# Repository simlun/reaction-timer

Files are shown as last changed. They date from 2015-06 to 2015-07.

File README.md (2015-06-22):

Reaction Timer
==============

A complete product based on Experiment 18 of [Make Electronics by Charles Platt][makeelec] - the Reaction Timer.

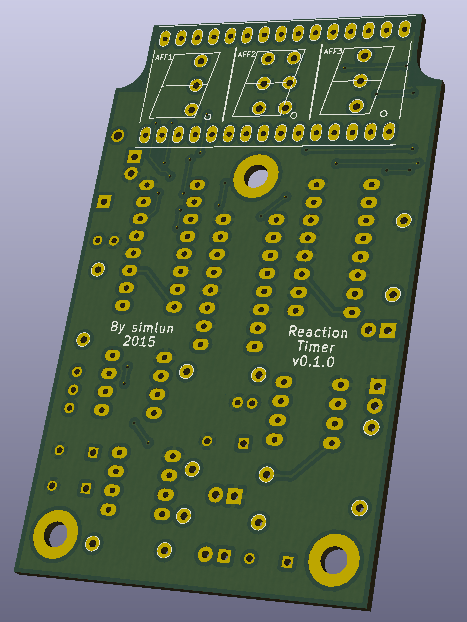
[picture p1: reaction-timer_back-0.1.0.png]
Back


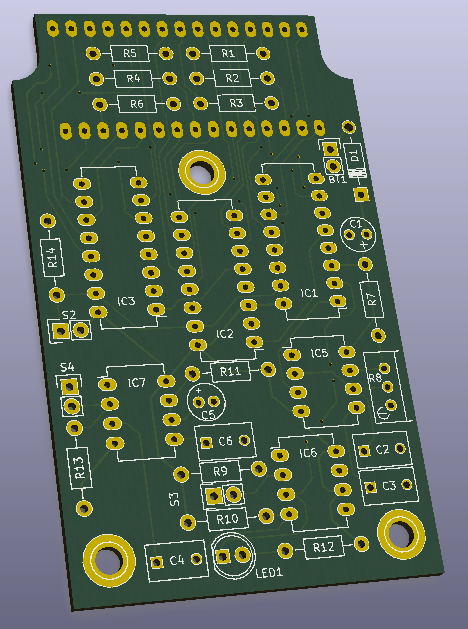
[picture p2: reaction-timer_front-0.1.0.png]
Front


My Modifications
----------------

* A real PCB design based on Platt's circuit diagrams and breadboarded version.
* Instead of `IC4`, the 3-in-1 package Platt is using, I'm using 3 separate 7-segment LED display modules (`IC4a-c`).
* I'm using a 5.6 kOhm `R12` as the current limiting resistor for the LED instead of Platt's 1 kOhms.
* There are two `R10`'s in the circuit diagram on [page 178][makeelec]. The one that is connected to `IC7` will be called `R13` here.

Bill Of Materials
-----------------

* Case: Hammond Manufacturing 1591CTCL clear polycarbonate box
* Power: 9 V battery connector cable
* `D1`: Reverse voltage protection 1N4004 diode

* `IC1`, `IC2`, `IC3`: DIP-16 4026 decade counters with 7-segment display driver
* `IC4a`, `IC4b`, `IC4c`: 7-segment 14 mm common cathode LED display
* `IC5`, `IC6`, `IC7`: DIP-8 555 timers

* `LED1`: Red LED

* `S2`, `S3`, `S4`: Normally open push buttons

* `C1`: 100 uF capacitor
* `C2`, `C3`, `C4`, `C6`: 0.1 uF capacitor
* `C5`: 10 uF capacitor

* `R1`, `R2`, `R3`, `R4`, `R5`, `R6`: 1 kOhm LED display current limiting resistors
* `R7`: 1 kOhm resistor for calibrating the clock timer (`IC5`)
* `R8`: 10 kOhm trimmer potentiometer for calibrating the clock timer (`IC5`)
* `R9`, `R10`, `R13`: 1 kOhm pull-up resistors
* `R14`: 1 kOhm pull-down resistor
* `R11`: 330 kOhm resistor for calibrating the delay timer (`IC7`)
* `R12`: 5.6 kOhm resistor

[makeelec]: http://www.amazon.com/Make-Electronics-Discovery-Charles-Platt/dp/0596153740

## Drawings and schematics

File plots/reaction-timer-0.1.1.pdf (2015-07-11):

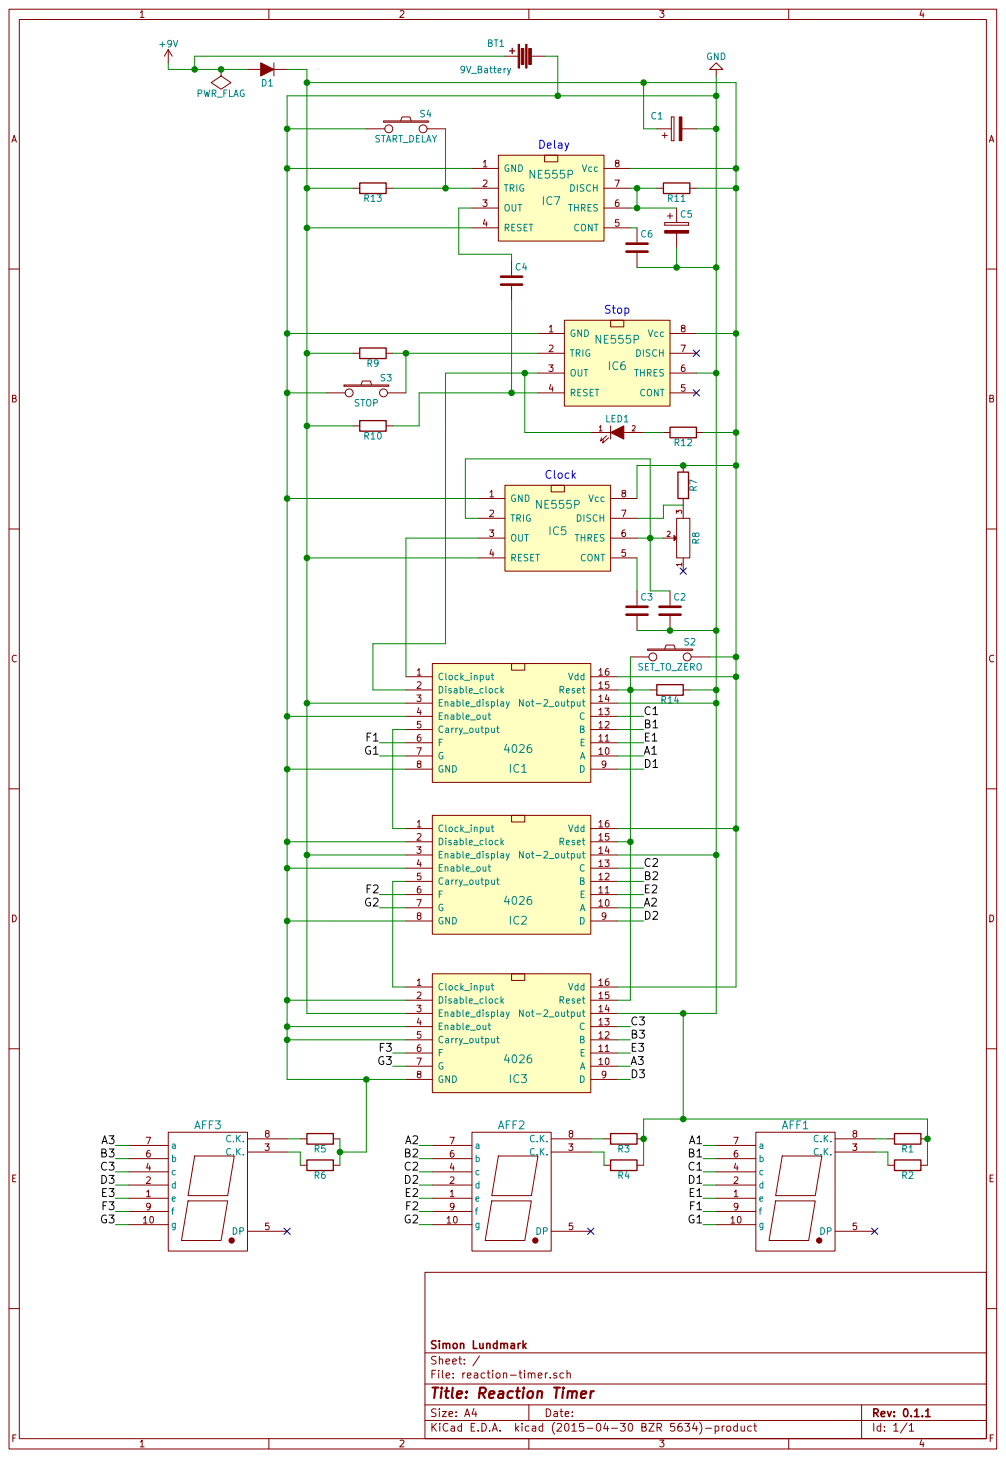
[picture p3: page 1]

Id: 1/1 Title: Reaction Timer File: reaction-timer.sch Sheet: / Simon Lundmark

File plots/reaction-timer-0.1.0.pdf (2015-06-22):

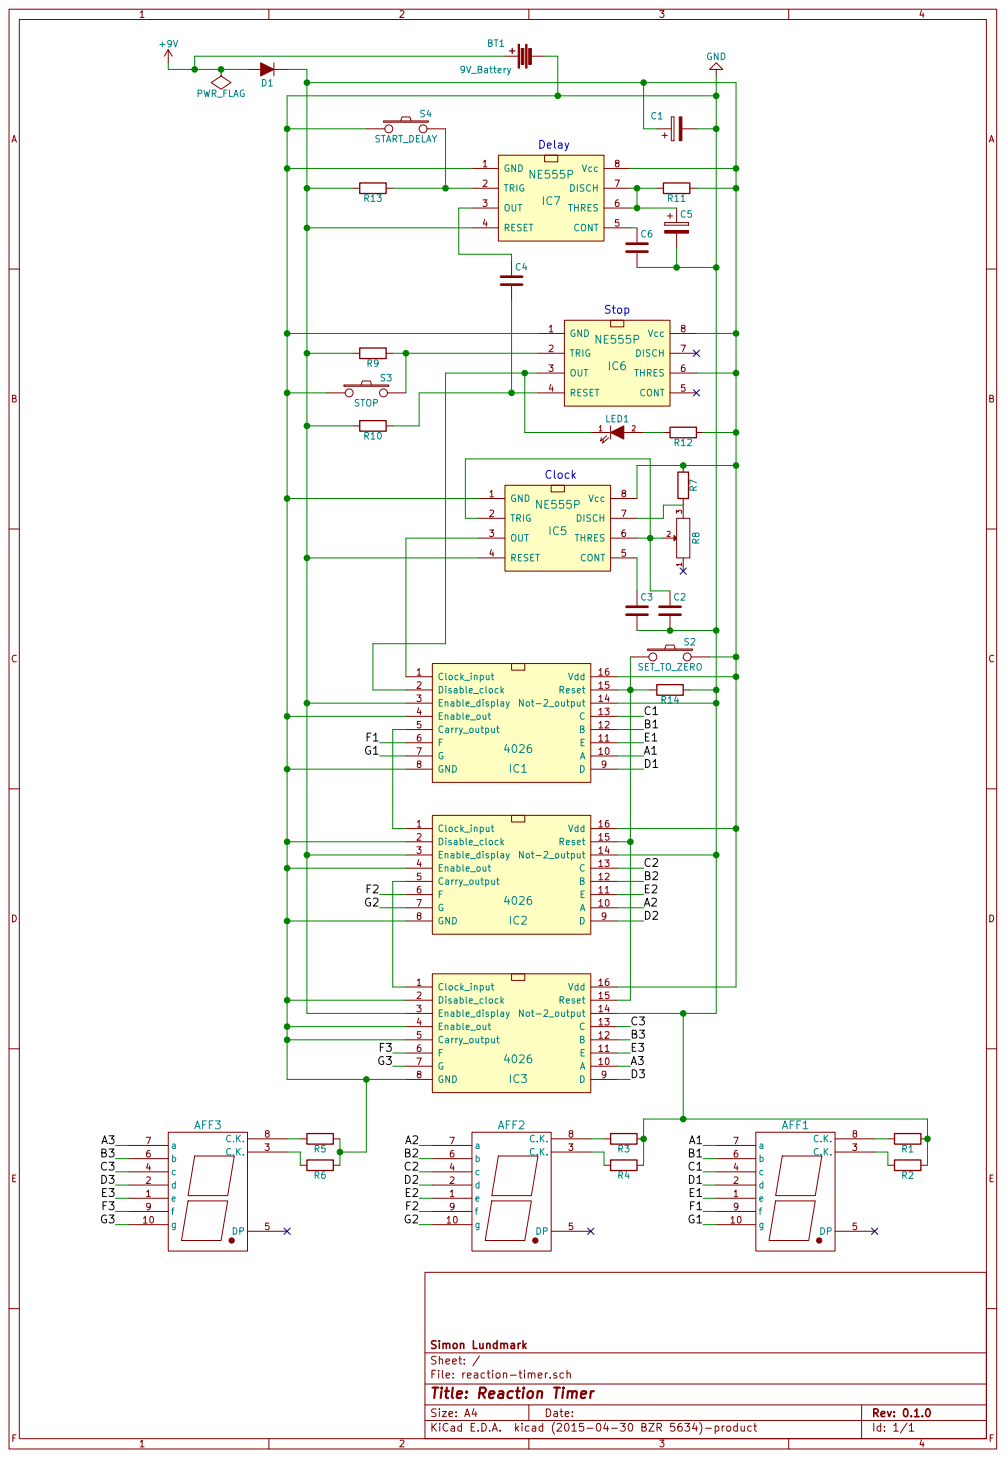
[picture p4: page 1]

Id: 1/1 Title: Reaction Timer File: reaction-timer.sch Sheet: / Simon Lundmark

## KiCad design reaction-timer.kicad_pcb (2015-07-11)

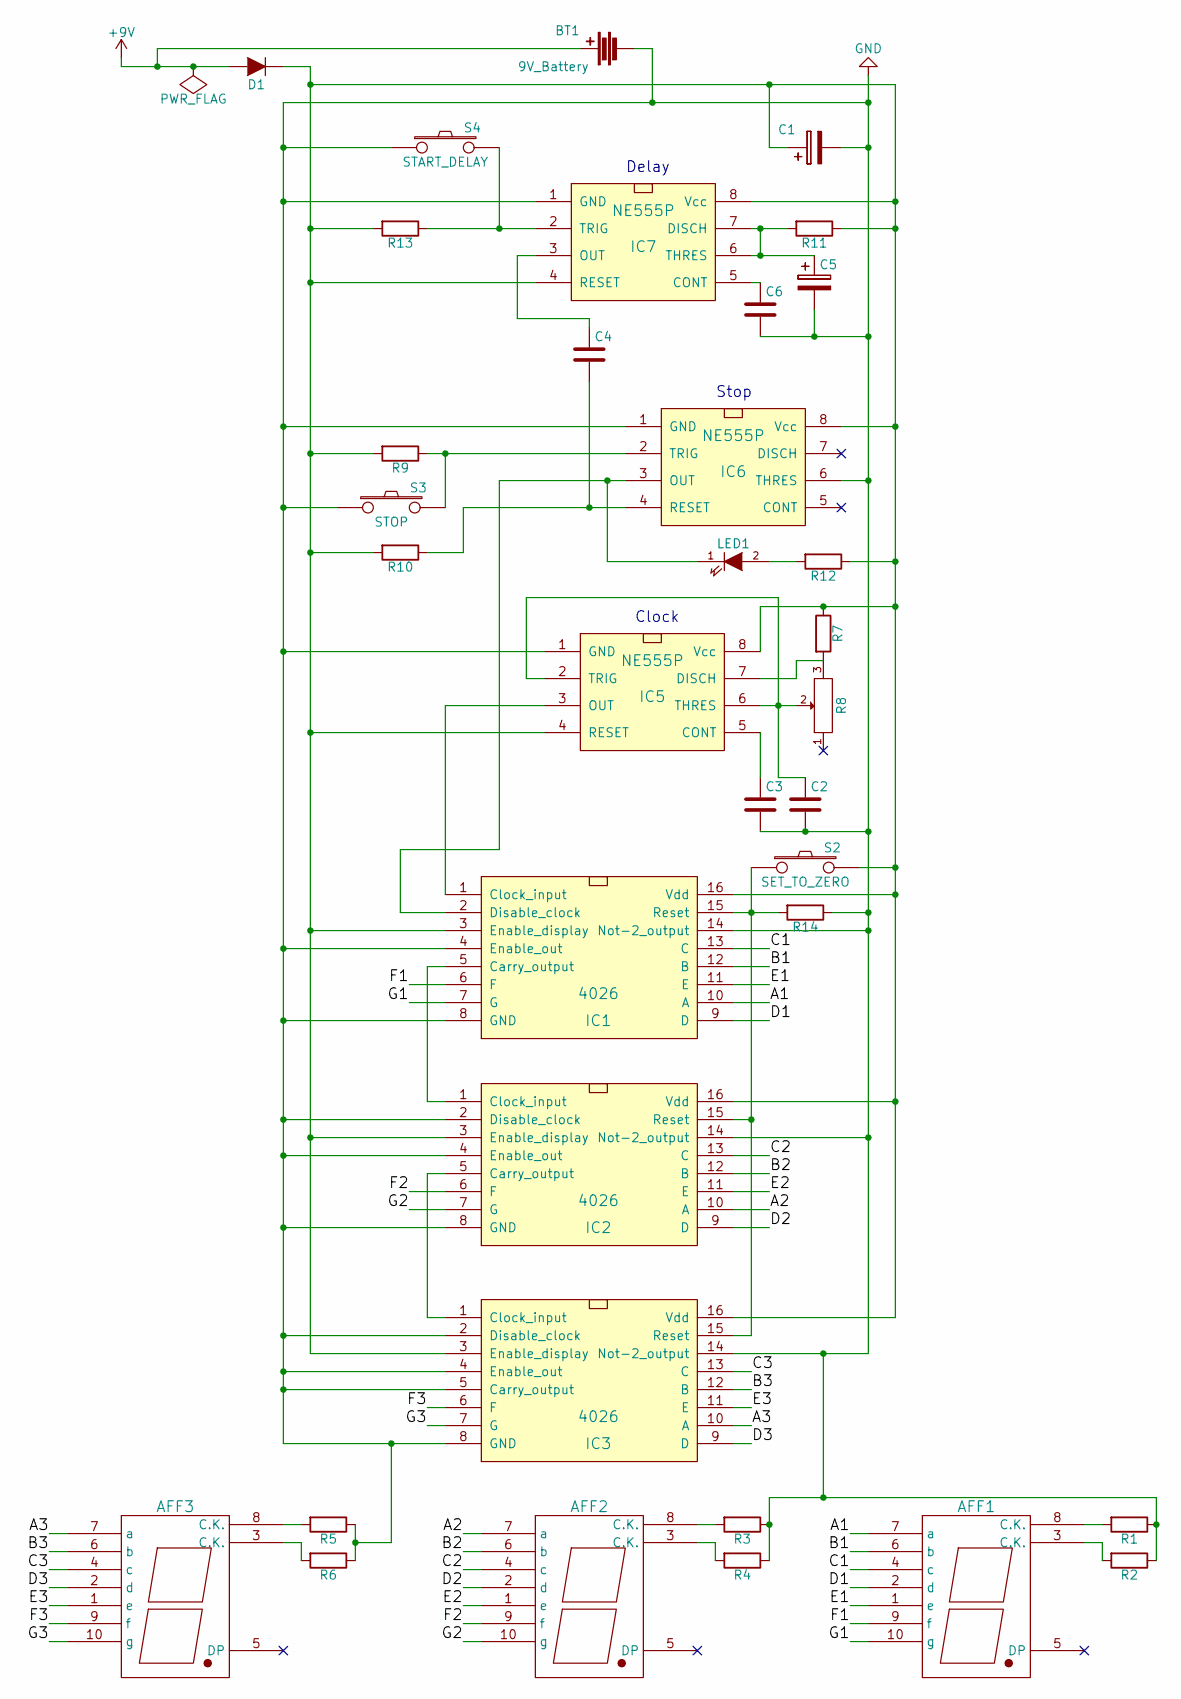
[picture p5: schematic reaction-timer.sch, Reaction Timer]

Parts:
AFF1, AFF2, AFF3: LTS-6980HR; 7SegmentLED_LTS6760_LTS6780
BT1: 9V_Battery; Pin_Header_Straight_1x02
C1: CP; Elko_vert_11x5mm_RM2.5
C2, C3, C4, C6: C; C_Disc_D7.5_P5
C5: CP; Elko_vert_11x5mm_RM2
D1: D; Diode_DO-41_SOD81_Horizontal_RM10
IC1, IC2, IC3: 4026; DIP-16_W7.62mm_LongPads
IC5, IC6, IC7: NE555P; DIP-8_W7.62mm_LongPads
LED1: LED; LED-5MM
R1, R2, R3, R4, R5, R6, R7, R9, R10, R11, R12, R13, R14: R; Resistor_Horizontal_RM10mm
R8: POT; Potentiometer_Bourns_3296W_3-8Zoll_Inline_ScrewUp
S2: SET_TO_ZERO; Pin_Header_Straight_1x02
S3: STOP; Pin_Header_Straight_1x02
S4: START_DELAY; Pin_Header_Straight_1x02

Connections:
+9V: BT1.1, D1.2 (A)
/A1: AFF1.7 (a), IC1.10 (A)
/A2: AFF2.7 (a), IC2.10 (A)
/A3: AFF3.7 (a), IC3.10 (A)
/B1: AFF1.6 (b), IC1.12 (B)
/B2: AFF2.6 (b), IC2.12 (B)
/B3: AFF3.6 (b), IC3.12 (B)
/C1: AFF1.4 (c), IC1.13 (C)
/C2: AFF2.4 (c), IC2.13 (C)
/C3: AFF3.4 (c), IC3.13 (C)
/D1: AFF1.2 (d), IC1.9 (D)
/D2: AFF2.2 (d), IC2.9 (D)
/D3: AFF3.2 (d), IC3.9 (D)
/E1: AFF1.1 (e), IC1.11 (E)
/E2: AFF2.1 (e), IC2.11 (E)
/E3: AFF3.1 (e), IC3.11 (E)
/F1: AFF1.9 (f), IC1.6 (F)
/F2: AFF2.9 (f), IC2.6 (F)
/F3: AFF3.9 (f), IC3.6 (F)
/G1: AFF1.10 (g), IC1.7 (G)
/G2: AFF2.10 (g), IC2.7 (G)
/G3: AFF3.10 (g), IC3.7 (G)
GND: BT1.2, C1.2, C2.2, C3.2, C5.2, C6.2, IC1.4 (Enable_out), IC1.8 (GND), IC1.14 (Not-2_output), IC2.2 (Disable_clock), IC2.4 (Enable_out), IC2.8 (GND), IC2.14 (Not-2_output), IC3.2 (Disable_clock), IC3.4 (Enable_out), IC3.5 (Carry_output), IC3.8 (GND), IC3.14 (Not-2_output), IC5.1 (GND), IC6.1 (GND), IC6.6 (THRES), IC7.1 (GND), R1.1, R2.1, R3.1, R4.1, R5.1, R6.1, R14.1, S3.1, S4.1
unnamed: AFF1.3 (C.K.), R2.2
unnamed: AFF1.8 (C.K.), R1.2
unnamed: AFF2.3 (C.K.), R4.2
unnamed: AFF2.8 (C.K.), R3.2
unnamed: AFF3.3 (C.K.), R6.2
unnamed: AFF3.8 (C.K.), R5.2
unnamed: C1.1, D1.1 (K), IC1.3 (Enable_display), IC1.16 (Vdd), IC2.3 (Enable_display), IC2.16 (Vdd), IC3.3 (Enable_display), IC3.16 (Vdd), IC5.4 (RESET), IC5.8 (Vcc), IC6.8 (Vcc), IC7.4 (RESET), IC7.8 (Vcc), R7.1, R9.2, R10.2, R11.1, R12.1, R13.2, S2.2
unnamed: C2.1, IC5.2 (TRIG), IC5.6 (THRES), R8.2
unnamed: C3.1, IC5.5 (CONT)
unnamed: C4.1, IC7.3 (OUT)
unnamed: C4.2, IC6.4 (RESET), R10.1
unnamed: C5.1, IC7.6 (THRES), IC7.7 (DISCH), R11.2
unnamed: C6.1, IC7.5 (CONT)
unnamed: IC1.1 (Clock_input), IC5.3 (OUT)
unnamed: IC1.2 (Disable_clock), IC6.3 (OUT), LED1.1 (K)
unnamed: IC1.5 (Carry_output), IC2.1 (Clock_input)
unnamed: IC1.15 (Reset), IC2.15 (Reset), IC3.15 (Reset), R14.2, S2.1
unnamed: IC2.5 (Carry_output), IC3.1 (Clock_input)
unnamed: IC5.7 (DISCH), R7.2, R8.3
unnamed: IC6.2 (TRIG), R9.1, S3.2
unnamed: IC7.2 (TRIG), R13.1, S4.2
unnamed: LED1.2 (A), R12.2

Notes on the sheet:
Delay
Stop
Clock

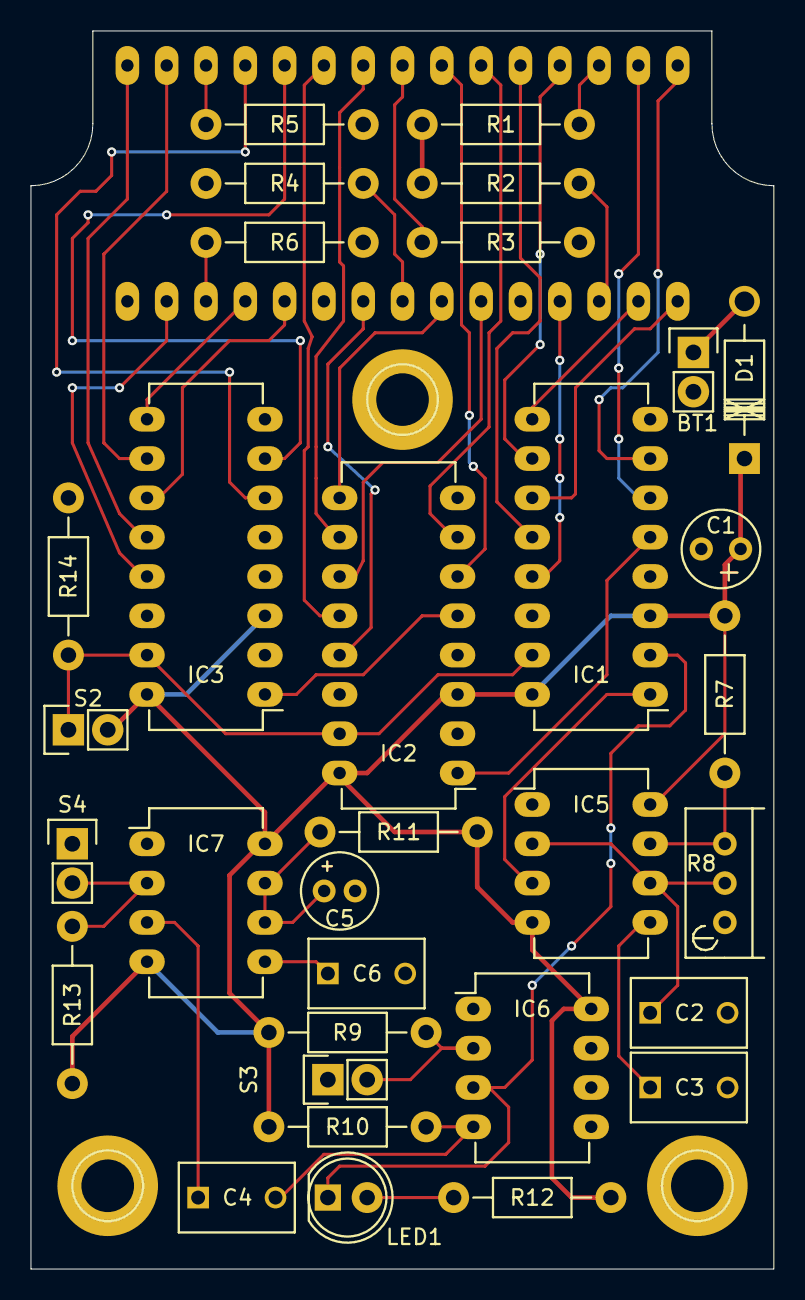
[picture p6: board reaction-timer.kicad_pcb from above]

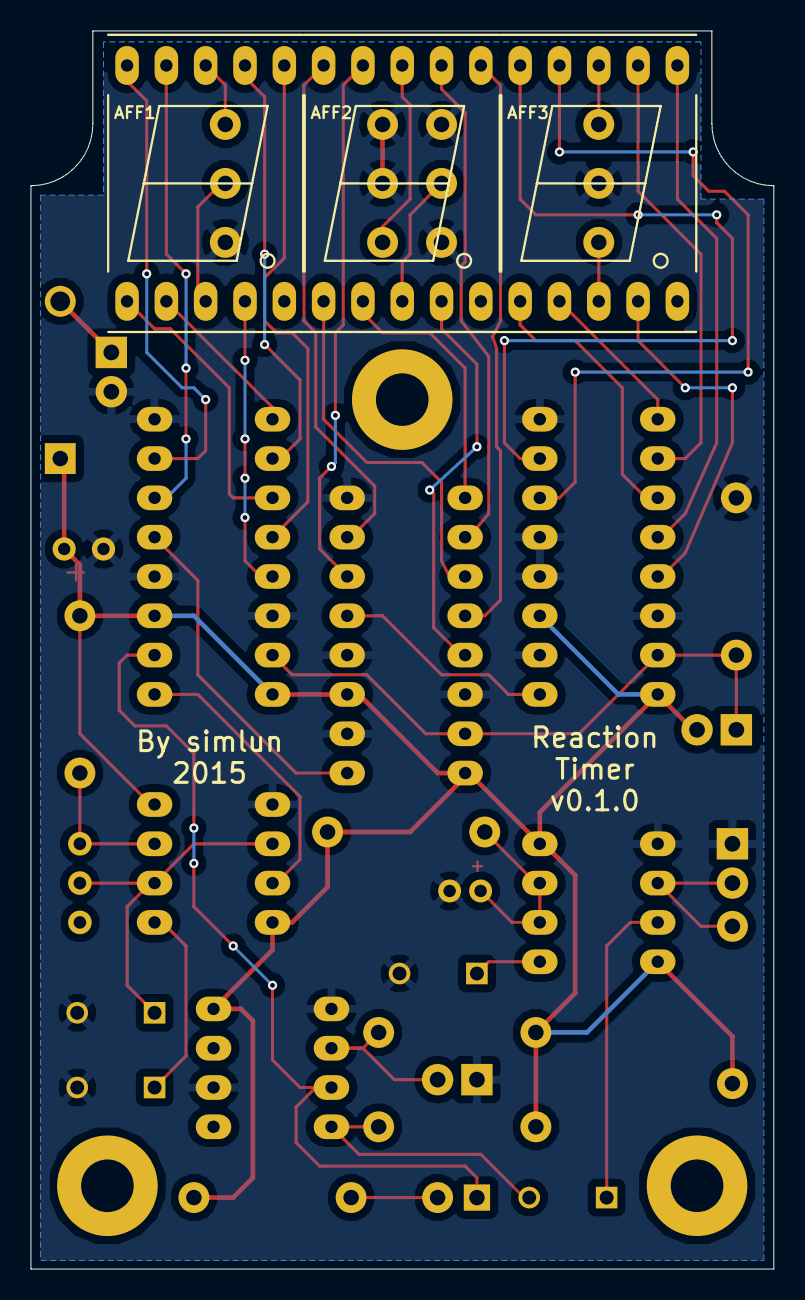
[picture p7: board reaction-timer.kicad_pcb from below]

Board: 2 copper layers, 48.0 x 80.0 mm, 35 parts (3 on the bottom side), 45 nets.

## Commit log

2015-06-07 Add initial readme and empty KiCad project
    [reaction-timer.sch]
2015-06-07 Add empty PCB layout
    [reaction-timer.kicad_pcb]
2015-06-07 Add 48x80 mm board edges
    [reaction-timer.kicad_pcb]
2015-06-07 Add the control section of the schematic
    [reaction-timer.sch]
2015-06-07 Add 4026 decade counters to schematic
    [reaction-timer.sch]
2015-06-07 Add 7-segment displays
    [reaction-timer.sch]
2015-06-07 Add connections to most significant digit display
    [reaction-timer.sch]
2015-06-08 Connect all 7-seg displays to driver chips
    [reaction-timer.sch]
2015-06-08 Fix bugs in connection labeling
    [reaction-timer.sch]
2015-06-08 Add reverse voltage protection diode
    [reaction-timer.sch]
2015-06-08 Add schematic rendered as PDF
2015-06-09 Associate displays, capacitors and diode to footprints
2015-06-09 Associate all footprints
2015-06-09 Associate last footprints and add battery
    [reaction-timer.sch]
2015-06-09 Change button footprints to pin header instead of wire pad
    [reaction-timer.sch]
2015-06-09 Read netlist
    [reaction-timer.kicad_pcb]
2015-06-09 Start placing footprints on board
    [reaction-timer.kicad_pcb]
2015-06-11 Add mounting holes to PCB
    [reaction-timer.kicad_pcb]
2015-06-11 Start connecting some ICs on the PCB to see if it's feasible
    [reaction-timer.kicad_pcb]
2015-06-13 Connect all display pins of IC3
    [reaction-timer.kicad_pcb]
2015-06-21 Place and connect IC2
    [reaction-timer.kicad_pcb]
2015-06-21 Place and connect IC1
    - Now all 7-seg displays are connected
    [reaction-timer.kicad_pcb]
2015-06-21 Place and connect S2 and R14
    [reaction-timer.kicad_pcb]
2015-06-21 Place and connect IC5
    [reaction-timer.kicad_pcb]
2015-06-21 Place and connect IC6
    [reaction-timer.kicad_pcb]
2015-06-21 Place IC7
    [reaction-timer.kicad_pcb]
2015-06-21 Connect IC7
    [reaction-timer.kicad_pcb]
2015-06-21 Move IC1 wiring
    [reaction-timer.kicad_pcb]
2015-06-21 Add +9V to the Power net class
    [reaction-timer.kicad_pcb]
2015-06-21 Connect +9V to filter cap C1
    [reaction-timer.kicad_pcb]
2015-06-21 Move power input
    [reaction-timer.kicad_pcb]
2015-06-22 Connect Vcc to the 7-seg display, but notice a problem!
    - I've connected the displays as common anode, not common cathode (as
    they should be).
    [reaction-timer.kicad_pcb]
2015-06-22 Fix 7-seg common anode/cathode schematic confusion
    [reaction-timer.sch]
2015-06-22 Fix PCB according to new netlist
    [reaction-timer.kicad_pcb]
2015-06-22 Connect Vcc everywhere
    [reaction-timer.kicad_pcb]
2015-06-22 Ground fill
    [reaction-timer.kicad_pcb]
2015-06-22 Move components to improve ground fill
    [reaction-timer.kicad_pcb]
2015-06-22 Move bottom layer trace to improve ground fill
    [reaction-timer.kicad_pcb]
2015-06-22 Adjust silkscreen text font size and placement
    [reaction-timer.kicad_pcb]
2015-06-22 Add silk screen text
    [reaction-timer.kicad_pcb]
2015-06-22 Plot Gerber files and drill file
    [reaction-timer.drl, reaction-timer.gbl, reaction-timer.gbo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]
2015-06-22 Finalize and package version 0.1.0
    [reaction-timer.drl, reaction-timer.gbl, reaction-timer.gbo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]
2015-07-11 Bugfix: IC6 pin 6 should be GND not VCC
    [reaction-timer.kicad_pcb, reaction-timer.sch]
2015-07-11 Add new bugfixed schematic
